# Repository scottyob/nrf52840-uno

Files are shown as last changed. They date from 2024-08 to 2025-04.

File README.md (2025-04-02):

# nrf52840-uno
A development board for the nRF52840 in a Uno form factor.  Idea is to test nRF52 components before using on larger projects.  Has USB-C support
and a LiPo charge controller.

Using the Holyiot 18010 module due to not wanting to have the know-how of antenna design just yet!

## Battery

Please ensure that a 1S LiPo battery is used with at least a capacity of 450mA (or ability to charge at a rate of 450mA)

## Flashing

Something like the Adafruit Pogo probe (4 pin version), can be used to flash this using SWD.  I used a rPi Pico and [DebugProbe](https://github.com/raspberrypi/debugprobe)

**Quickstart:**
```
openocd -f interface/cmsis-dap.cfg -f target/nrf52.cfg -c "init"
[scott@sob-desktop Adafruit_Adalink]$ openocd -f interface/cmsis-dap.cfg -f target/nrf52.cfg -c "init"
Open On-Chip Debugger 0.12.0
Licensed under GNU GPL v2
For bug reports, read
	http://openocd.org/doc/doxygen/bugs.html
Info : auto-selecting first available session transport "swd". To override use 'transport select <transport>'.
Info : Using CMSIS-DAPv2 interface with VID:PID=0x2e8a:0x000c, serial=E66130100F7FA32B
Info : CMSIS-DAP: SWD supported
Info : CMSIS-DAP: Atomic commands supported
Info : CMSIS-DAP: Test domain timer supported
Info : CMSIS-DAP: FW Version = 2.0.0
Info : CMSIS-DAP: Interface Initialised (SWD)
Info : SWCLK/TCK = 0 SWDIO/TMS = 0 TDI = 0 TDO = 0 nTRST = 0 nRESET = 0
Info : CMSIS-DAP: Interface ready
Info : clock speed 1000 kHz
Info : SWD DPIDR 0x2ba01477
Info : [nrf52.cpu] Cortex-M4 r0p1 processor detected
Info : [nrf52.cpu] target has 6 breakpoints, 4 watchpoints
Info : starting gdb server for nrf52.cpu on 3333
Info : Listening on port 3333 for gdb connections
Info : Listening on port 6666 for tcl connections
Info : Listening on port 4444 for telnet connections

(seperate terminal)
(env) [scott@sob-desktop local-scott]$ telnet localhost 4444
Trying ::1...
telnet: connect to address ::1: Connection refused
Trying 127.0.0.1...
Connected to localhost.
Escape character is '^]'.
Open On-Chip Debugger
> nrf5 info
nRF52840-xxAA(build code: D0) 1024kB Flash, 256kB RAM

halt
nrf5 mass_erase
flash write_image pca10056_bootloader-0.2.11_s140_6.1.1.hex
flash verify_image pca10056_bootloader-0.2.11_s140_6.1.1.hex
reset run

```

Programming with Arduino:
```
Adafruit mRF52 -> Nordic nRF52840 DK (ours is similar to this)
Tools -> Programmer -> Bootloader DFU
Burn Bootloader
```

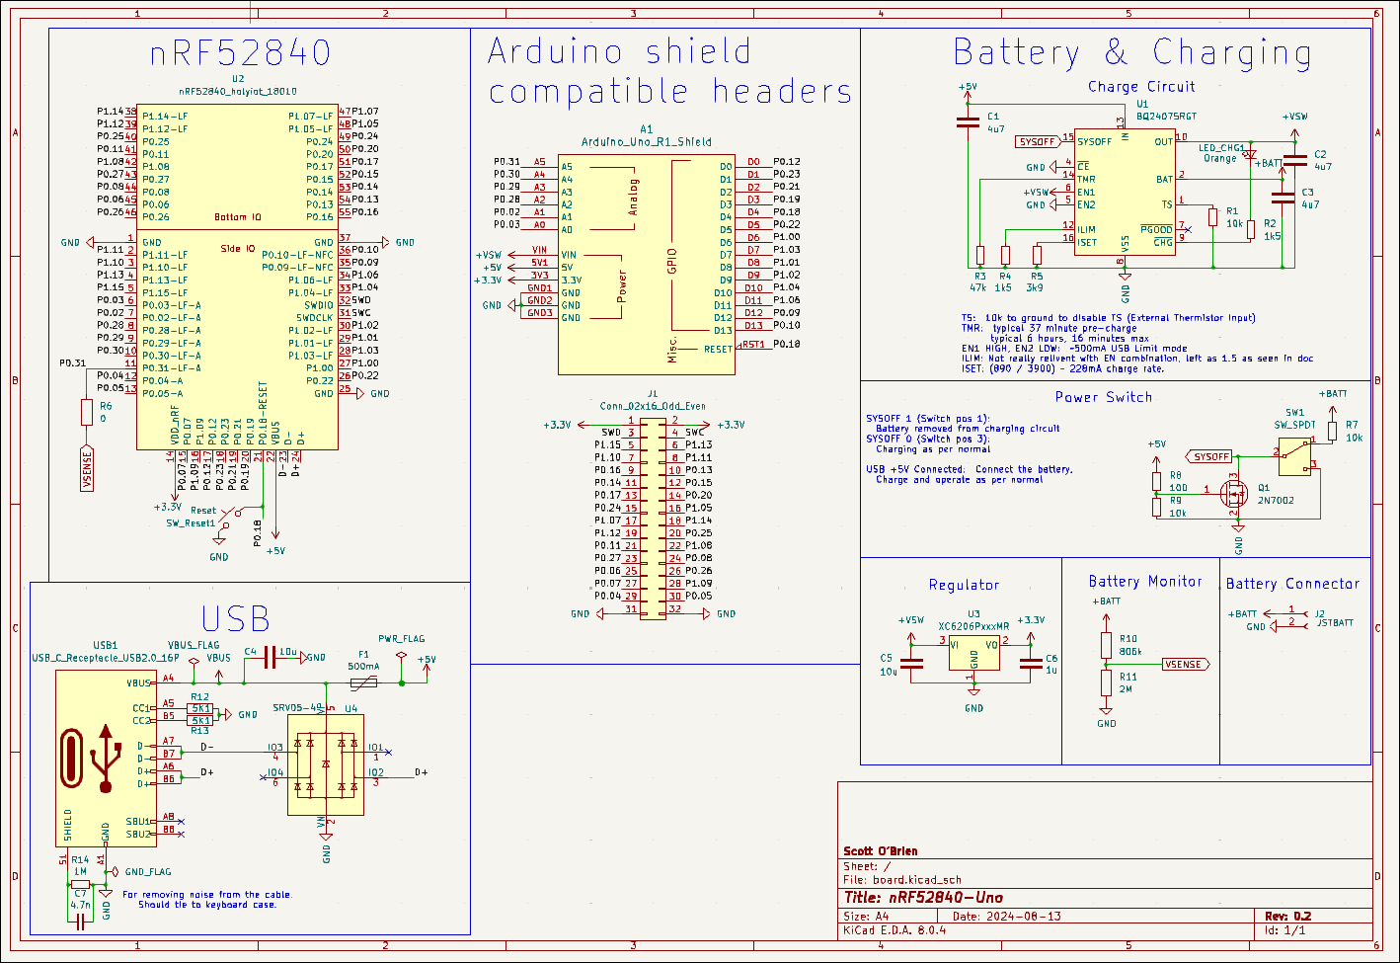
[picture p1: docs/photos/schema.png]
Schema

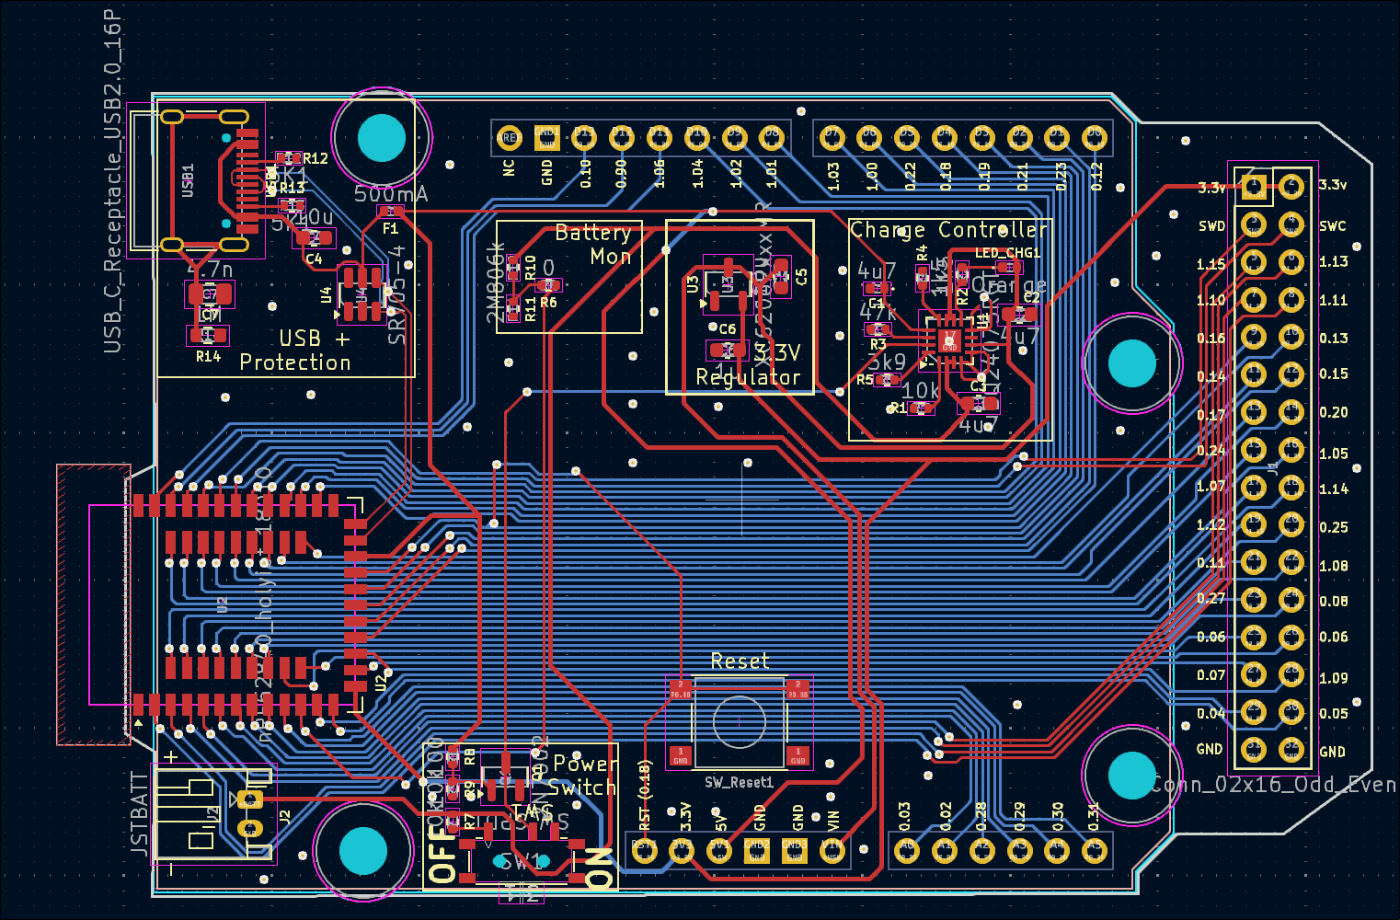
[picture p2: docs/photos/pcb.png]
PCB


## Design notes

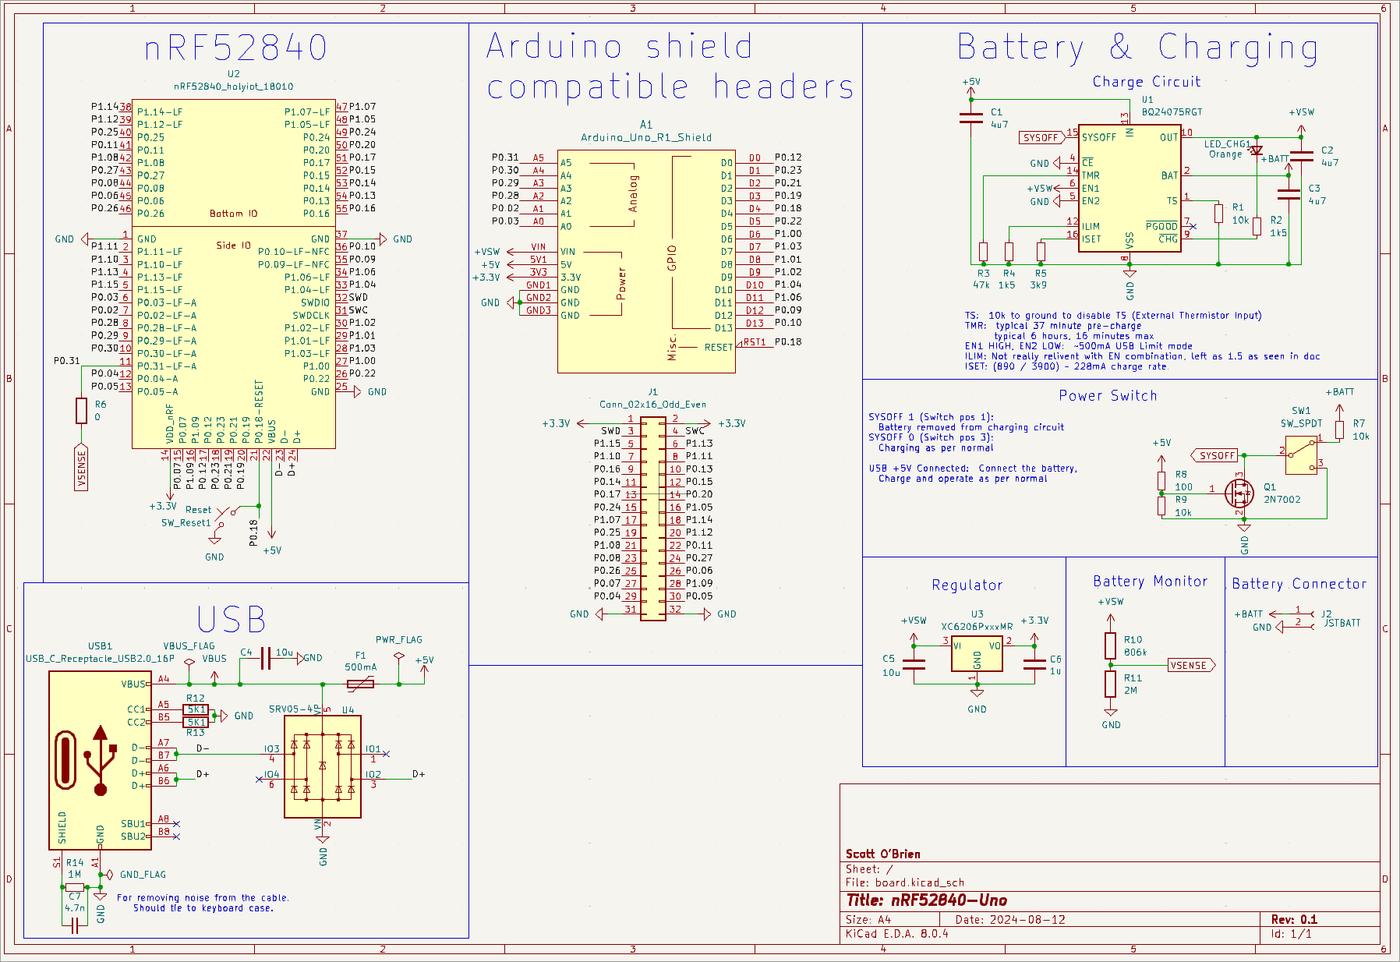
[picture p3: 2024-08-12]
docs/photos/schema_rev0.1.png

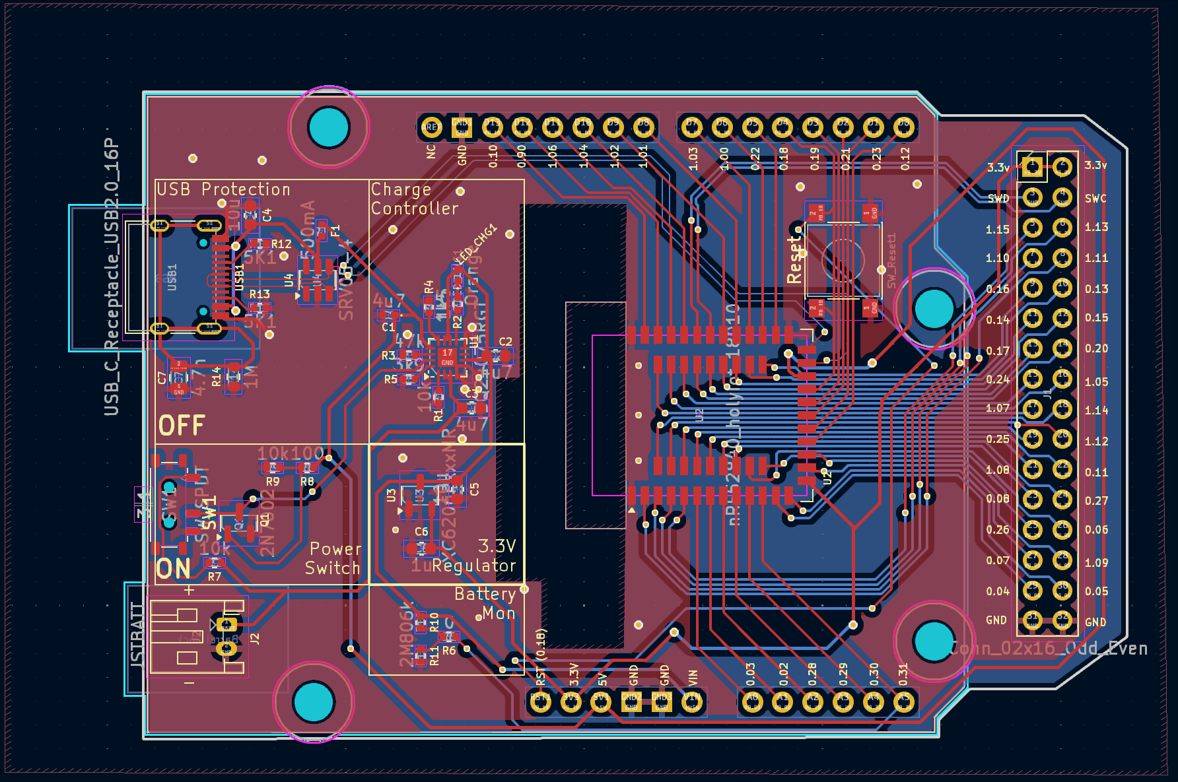
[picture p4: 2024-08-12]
docs/photos/pcb_rev0.1.png

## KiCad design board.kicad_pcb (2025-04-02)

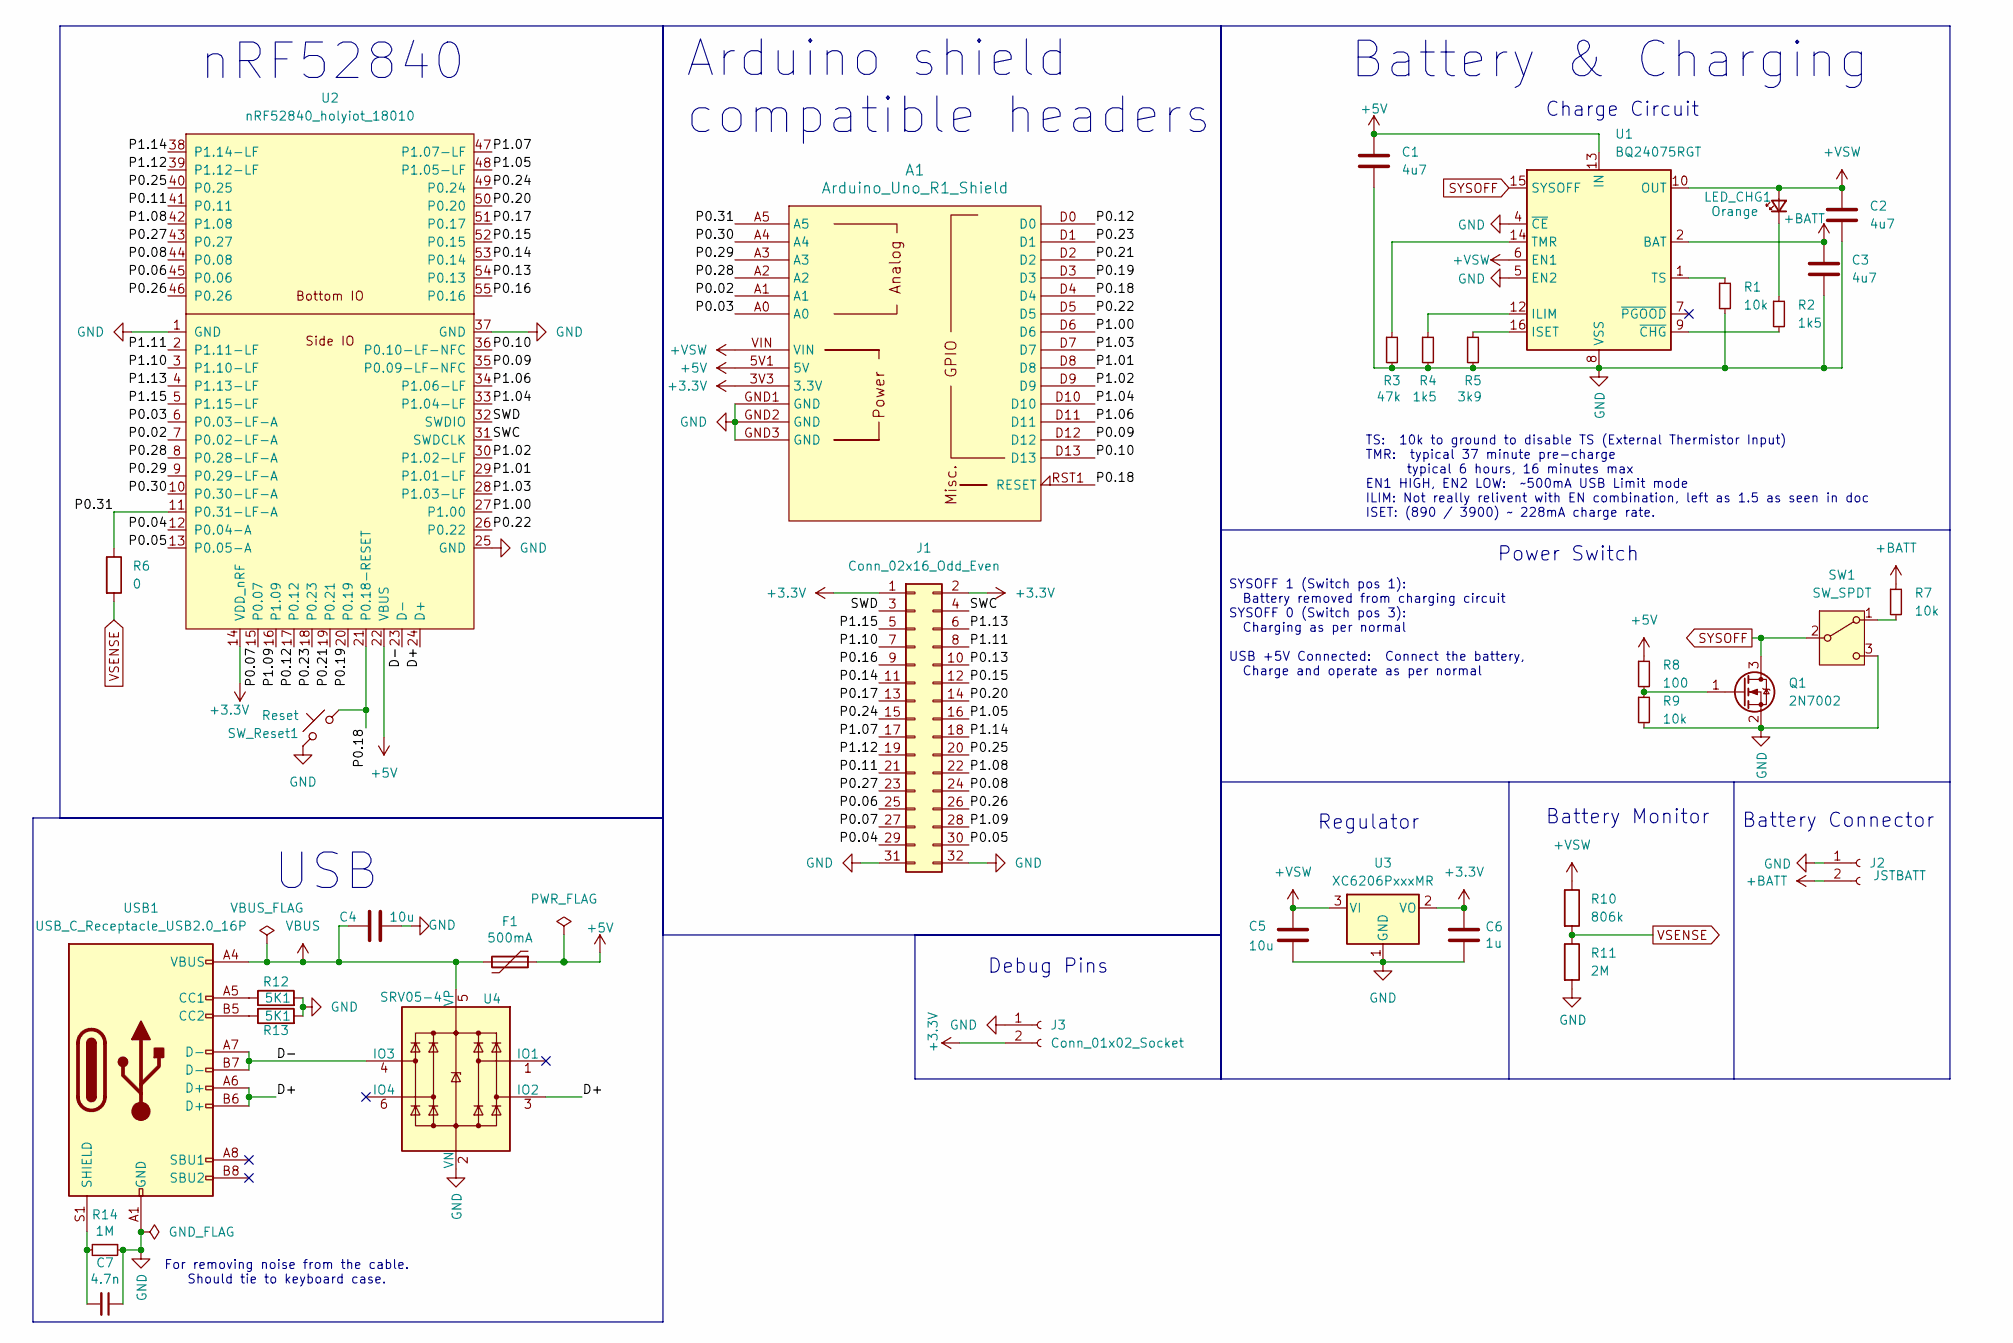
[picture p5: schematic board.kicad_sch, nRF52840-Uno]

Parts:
A1: Arduino_Uno_R1_Shield; Arduino_Uno_R2_Shield
C1, C2, C3: 4u7; C_0603_1608Metric
C4, C5: 10u; C_0603_1608Metric; MPN CL10A106KP8NNNC; JLCSMT C19702
C6: 1u; C_0603_1608Metric; MPN CL10A105KB8NNNC; LCSC C15849
C7: 4.7n; C_0805_2012Metric
F1: 500mA; Fuse_0805_2012Metric; MPN SMD0805-050; JLCSMT C66452
J1: Conn_02x16_Odd_Even; PinHeader_2x16_P2.54mm_Vertical
J2: JSTBATT; JST_PH_S2B-PH-K_1x02_P2.00mm_Horizontal
J3: Conn_01x02_Socket; PinHeader_1x02_P2.54mm_Vertical
LED_CHG1: Orange; LED_0603_1608Metric_Pad1.05x0.95mm_HandSolder
Q1: 2N7002; SOT-23
R1, R7, R9: 10k; R_0603_1608Metric_Pad0.98x0.95mm_HandSolder
R2, R4: 1k5; R_0603_1608Metric_Pad0.98x0.95mm_HandSolder
R3: 47k; R_0603_1608Metric_Pad0.98x0.95mm_HandSolder
R5: 3k9; R_0603_1608Metric_Pad0.98x0.95mm_HandSolder
R6: 0; R_0603_1608Metric_Pad0.98x0.95mm_HandSolder
R8: 100; R_0603_1608Metric_Pad0.98x0.95mm_HandSolder
R10: 806k; R_0603_1608Metric_Pad0.98x0.95mm_HandSolder
R11: 2M; R_0603_1608Metric_Pad0.98x0.95mm_HandSolder
R12, R13: 5K1; R_0603_1608Metric_Pad0.98x0.95mm_HandSolder
R14: 1M; R_0603_1608Metric_Pad0.98x0.95mm_HandSolder
SW1: SW_SPDT; SW_MSK12C02-HB
SW_Reset1: Reset; SW_Push_1P1T_NO_6x6mm_H9.5mm
U1: BQ24075RGT; VQFN-16-1EP_3x3mm_P0.5mm_EP1.6x1.6mm
U2: nRF52840_holyiot_18010
U3: XC6206PxxxMR; SOT-23-3
U4: SRV05-4; SOT-23-6; MPN SRV05-4-P-T7; JLCSMT C85364
USB1: USB_C_Receptacle_USB2.0_16P; USB_C_Receptacle_HRO_TYPE-C-31-M-12

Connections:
+3.3V: A1.3V3 (3.3V), C6.2, J1.1, J1.2, J3.2, U2.14 (VDD_nRF), U3.2 (VO)
+5V: A1.5V1 (5V), C1.1, F1.1, R8.1, U1.13 (IN), U2.22 (VBUS)
+BATT: C3.1, J2.2, R7.1, U1.2 (BAT), U1.3 (BAT)
+VSW: A1.VIN, C2.1, C5.1, LED_CHG1.2 (A), R10.1, U1.6 (EN1), U1.10 (OUT), U1.11 (OUT), U3.3 (VI)
/D+: U2.24 (D+), U4.3 (IO2), USB1.A6 (D+), USB1.B6 (D+)
/D-: U2.23 (D-), U4.4 (IO3), USB1.A7 (D-), USB1.B7 (D-)
/P0.02: A1.A1, U2.7 (P0.02-LF-A)
/P0.03: A1.A0, U2.6 (P0.03-LF-A)
/P0.04: J1.29, U2.12 (P0.04-A)
/P0.05: J1.30, U2.13 (P0.05-A)
/P0.06: J1.25, U2.45 (P0.06)
/P0.07: J1.27, U2.15 (P0.07)
/P0.08: J1.24, U2.44 (P0.08)
/P0.09: A1.D12, U2.35 (P0.09-LF-NFC)
/P0.10: A1.D13, U2.36 (P0.10-LF-NFC)
/P0.11: J1.21, U2.41 (P0.11)
/P0.12: A1.D0, U2.17 (P0.12)
/P0.13: J1.10, U2.54 (P0.13)
/P0.14: J1.11, U2.53 (P0.14)
/P0.15: J1.12, U2.52 (P0.15)
/P0.16: J1.9, U2.55 (P0.16)
/P0.17: J1.13, U2.51 (P0.17)
/P0.18: A1.D4, A1.RST1 (RESET), SW_Reset1.2, U2.21 (P0.18-RESET)
/P0.19: A1.D3, U2.20 (P0.19)
/P0.20: J1.14, U2.50 (P0.20)
/P0.21: A1.D2, U2.19 (P0.21)
/P0.22: A1.D5, U2.26 (P0.22)
/P0.23: A1.D1, U2.18 (P0.23)
/P0.24: J1.15, U2.49 (P0.24)
/P0.25: J1.20, U2.40 (P0.25)
/P0.26: J1.26, U2.46 (P0.26)
/P0.27: J1.23, U2.43 (P0.27)
/P0.28: A1.A2, U2.8 (P0.28-LF-A)
/P0.29: A1.A3, U2.9 (P0.29-LF-A)
/P0.30: A1.A4, U2.10 (P0.30-LF-A)
/P0.31: A1.A5, R6.1, U2.11 (P0.31-LF-A)
/P1.00: A1.D6, U2.27 (P1.00)
/P1.01: A1.D8, U2.29 (P1.01-LF)
/P1.02: A1.D9, U2.30 (P1.02-LF)
/P1.03: A1.D7, U2.28 (P1.03-LF)
/P1.04: A1.D10, U2.33 (P1.04-LF)
/P1.05: J1.16, U2.48 (P1.05-LF)
/P1.06: A1.D11, U2.34 (P1.06-LF)
/P1.07: J1.17, U2.47 (P1.07-LF)
/P1.08: J1.22, U2.42 (P1.08)
/P1.09: J1.28, U2.16 (P1.09)
/P1.10: J1.7, U2.3 (P1.10-LF)
/P1.11: J1.8, U2.2 (P1.11-LF)
/P1.12: J1.19, U2.39 (P1.12-LF)
/P1.13: J1.6, U2.4 (P1.13-LF)
/P1.14: J1.18, U2.38 (P1.14-LF)
/P1.15: J1.5, U2.5 (P1.15-LF)
/SWC: J1.4, U2.31 (SWDCLK)
/SWD: J1.3, U2.32 (SWDIO)
GND: A1.GND1 (GND), A1.GND2 (GND), A1.GND3 (GND), C1.2, C2.2, C3.2, C4.1, C5.2, C6.1, C7.1, J1.31, J1.32, J2.1, J3.1, Q1.2 (S), R1.2, R3.2, R4.2, R5.2, R9.2, R11.2, R12.2, R13.2, R14.1, SW1.3 (C), SW_Reset1.1, U1.4 (~CE), U1.5 (EN2), U1.8 (VSS), U1.17 (VSS), U2.1 (GND), U2.25 (GND), U2.37 (GND), U3.1 (GND), U4.2 (VN), USB1.A1 (GND), USB1.A12 (GND), USB1.B1 (GND), USB1.B12 (GND)
unnamed: LED_CHG1.1 (K), R2.1
unnamed: Q1.1 (G), R8.2, R9.1
unnamed: R7.2, SW1.1 (A)
unnamed: R4.1, U1.12 (ILIM)
unnamed: R5.1, U1.16 (ISET)
unnamed: R3.1, U1.14 (TMR)
unnamed: R1.1, U1.1 (TS)
unnamed: R2.2, U1.9 (~CHG)
unnamed: R12.1, USB1.A5 (CC1)
unnamed: R13.1, USB1.B5 (CC2)
unnamed: C7.2, R14.2, USB1.S1 (SHIELD)
SYSOFF: Q1.3 (D), SW1.2 (B), U1.15 (SYSOFF)
VBUS: C4.2, F1.2, U4.5 (VP), USB1.A4 (VBUS), USB1.A9 (VBUS), USB1.B4 (VBUS), USB1.B9 (VBUS)
VSENSE: R6.2, R10.2, R11.1

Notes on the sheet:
USB
Regulator
SYSOFF 1 (Switch pos 1): Battery removed from charging circuit SYSOFF 0 (Switch pos 3): Charging as per normal USB +5V Connected: Connect the battery, Charge and operate as per normal
TS: 10k to ground to disable TS (External Thermistor Input) TMR: typical 37 minute pre-charge typical 6 hours, 16 minutes max EN1 HIGH, EN2 LOW: ~500mA USB Limit mode ILIM: Not really relivent with EN combination, left as 1.5 as seen in doc ISET: (890 / 3900) ~ 228mA charge rate.
Battery & Charging
Battery Connector
Battery Monitor
Charge Circuit
For removing noise from the cable. Should tie to keyboard case.
Arduino shield compatible headers
Debug Pins
Power Switch
nRF52840

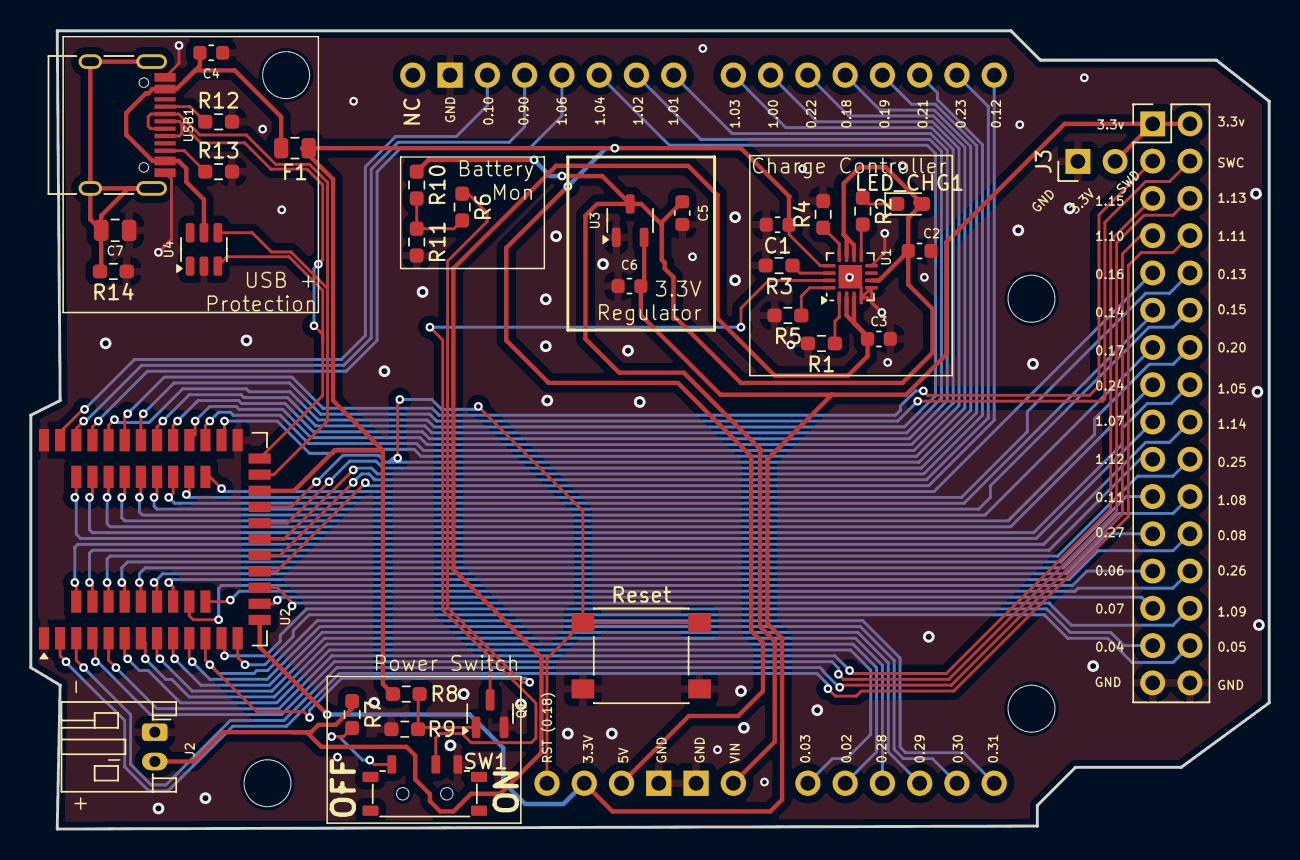
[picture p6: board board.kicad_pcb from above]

Board: 2 copper layers, 84.4 x 54.4 mm, 35 parts (0 on the bottom side), 69 nets.

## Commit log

2024-08-13 Updated to revision 0.2, with Holyiot module on edge of board
    [board.kicad_pcb, board.kicad_sch]
2024-08-13 Updated silkscreen
    [board.kicad_pcb]
2024-09-03 Added debug / programming pins
    [board.kicad_pcb, board.kicad_sch]
2025-04-02 Updated readme. Fixed silkscreen
    [board.kicad_pcb]
2025-04-02 Fixed polarity of connector
    [board.kicad_pcb, board.kicad_sch]
